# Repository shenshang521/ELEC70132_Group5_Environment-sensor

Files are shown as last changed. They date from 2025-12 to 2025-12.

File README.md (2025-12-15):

Environmental Sensor Board Files
Imperial College London, Dep. of Electrical and Electronic Engineering,
ELEC70132 - Laboratory in Sensor Systems, Group 5
------------------------------------------------------------------------
# ESP32 Environmental Sensor Hub & IoT Data System

## Project Overview
This repository contains the source code and documentation for an ESP32-based Environmental Sensor Hub. This project is submitted as part of the MSc coursework at **Imperial College London**.

The system is a complete **IoT solution** that integrates:
1.  **Edge Device (ESP32):** Monitors environmental conditions (BME680), air quality, distance (ToF), and geolocation (GPS).
2.  **Web Interface:** Hosted directly on the ESP32 for real-time visualization.
3.  **PC Integration (Python):** A desktop application to wirelessly collect sensor data into a database and export it for analysis (Excel/CSV).

## Key Features
*   **Multi-Sensor Fusion:** Reads Temperature, Humidity, Pressure, Gas Resistance (IAQ), Distance, and GPS location simultaneously.
*   **Real-Time Web Dashboard:** Uses **Server-Sent Events (SSE)** to push data to browsers without page refreshes.
*   **Wireless Data Logging (Python):** Python scripts allow for long-term data collection over WiFi into an SQLite database.
*   **Data Analysis Ready:** Includes a tool to export database records to `.csv` format for Excel/MATLAB analysis.
*   **Local Backup:** Automated CSV logging to an onboard SD card for redundancy.
*   **Visual Feedback:** OLED display showing status, IP address, and sensor readings.

## Hardware Requirements
*   **Microcontroller:** ESP32 Development Board
*   **Sensors:** Adafruit BME680, VL53L4CX (ToF), GPS Module (I2C)
*   **Display:** SSD1306 128x64 OLED (I2C)
*   **Storage:** MicroSD Card Module
*   **Connectivity:** WiFi (2.4GHz)

## Dependencies (Arduino IDE)
Please install the following libraries via the Arduino Library Manager:
*   ESPAsyncWebServer
*   AsyncTCP
*   Adafruit SSD1306
*   Adafruit GFX
*   Adafruit BME680 Library
*   Adafruit GPS Library
*   VL53L4CX

## Pin Configuration
| Component | ESP32 Pin | Protocol | Notes |
|---|---|---|---|
| **OLED Display** | SDA / SCL | I2C | Address: 0x3D |
| **BME680** | SDA / SCL | I2C | Default Address |
| **VL53L4CX** | SDA / SCL | I2C | Default Address |
| **GPS Module** | SDA / SCL | I2C | Address: 0x10 |
| **SD Card CS** | GPIO 5 | SPI | Chip Select |
| **SD Card SCK** | GPIO 18 | SPI | VSPI |
| **SD Card MISO** | GPIO 19 | SPI | VSPI |
| **SD Card MOSI** | GPIO 23 | SPI | VSPI |

## Setup Instructions

### ESP32 Configuration
1. Open `src/main/secrets.h`.
2. Replace `YOUR_WIFI_SSID` and `YOUR_WIFI_PASSWORD` with your actual WiFi credentials before flashing the code.
3. Upload the code to your ESP32.
4. Note the IP Address displayed on the OLED screen after startup.

### Python Configuration
1. Open `python_scripts/receive.py`.
2. Find the `ESP32_IP` variable (or URL setting).
3. Update it to match the IP address shown on your ESP32's OLED screen.
4. Run the script to start logging data.

## Project Structure
```text
ESP32_Sensor_Project/
├── src/
│   └── main/                  # Arduino Sketch Folder
│       ├── main.ino           # Main Firmware
│       ├── secrets.h          # WiFi Credentials (Template)
│       └── index_html.h       # Web Frontend (HTML/JS)
├── python_scripts/
│   ├── receive.py             # Rx Data from ESP32 -> SQLite DB
│   └── export_data.py         # Convert DB -> CSV/Excel
├── docs/
│   └── Environmental Sensor Report - Final.pdf             # Coursework Report
├── hardware/
│   └── Environmental_PCB_Group5.epro  # PCB Design 
└── README.md                  # Documentation
├── previous code/             # Development History & Iterations
│   ├── Cali_friday            # Initial sensor calibration tests
│   ├── Calibriation_Environment_sensor # Detailed calibration logic
│   ├── Environment_WIFI_SD_HTML # Early integration (Web+SD)
│   ├── environment            # Basic environmental sensor drivers
│   ├── python_scripts         # Legacy/Old Python scripts
│   └── sd_tof                 # Distance sensor & SD 
├── 3D Enclosure/              # Mechanical Design Files (.stl)
│   ├── PCB_Enclosure_Body.stl # Main housing for electronics
│   ├── PCB_Cover.stl          # Lid for the sensor unit
│   ├── Power_bank_body.stl    # Holder for external battery
│   └── Power_bank_cover.stl   # Lid for the battery

The original intention for this project was was to develop a single-PCB
sensor system capable of wired and wireless communication (via a Wi-Fi
connection). All the relevant files for this project can be found in
this public GitHub repository, including the final report.

For more details, feel free to contact: tr525@ic.ac.uk

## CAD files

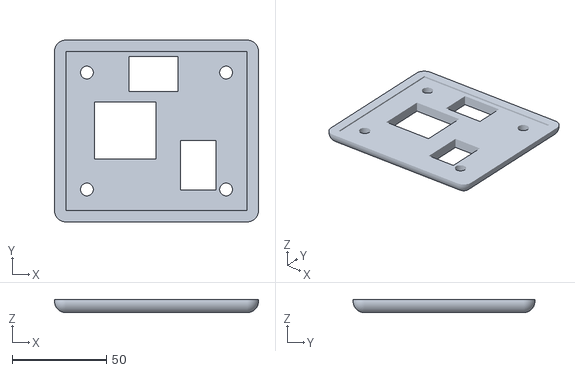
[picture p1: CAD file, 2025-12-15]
3D Enclosure/PCB_Cover.stl
108.5 x 96.7 x 7.00

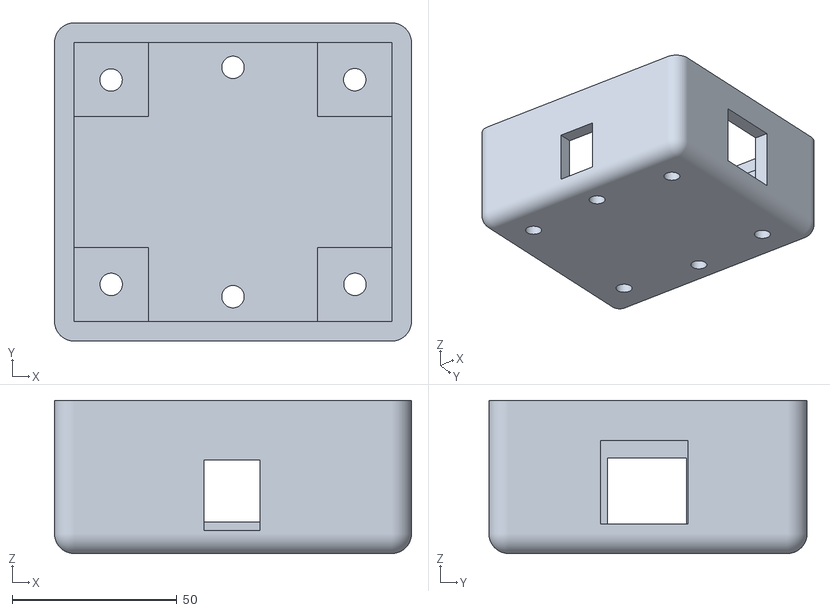
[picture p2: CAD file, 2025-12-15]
3D Enclosure/PCB_Enclosure_Body.stl
108.5 x 96.7 x 46.5

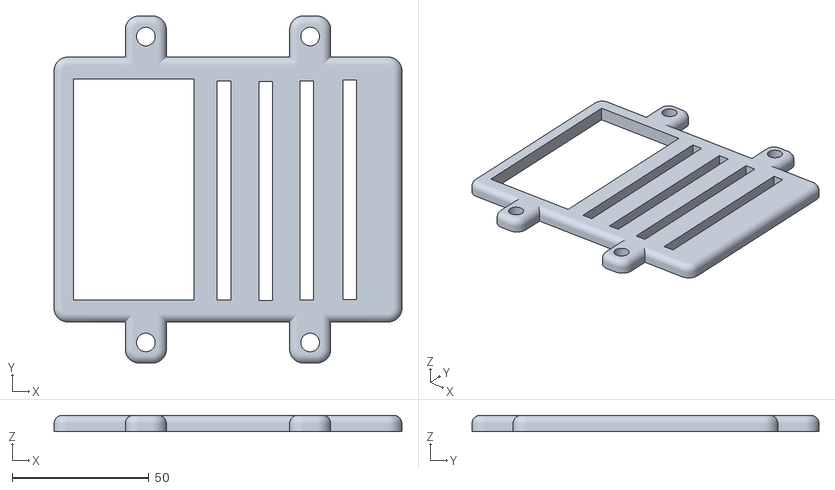
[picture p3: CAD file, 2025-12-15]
3D Enclosure/Power_bank_cover.stl
127.0 x 126.7 x 6.00

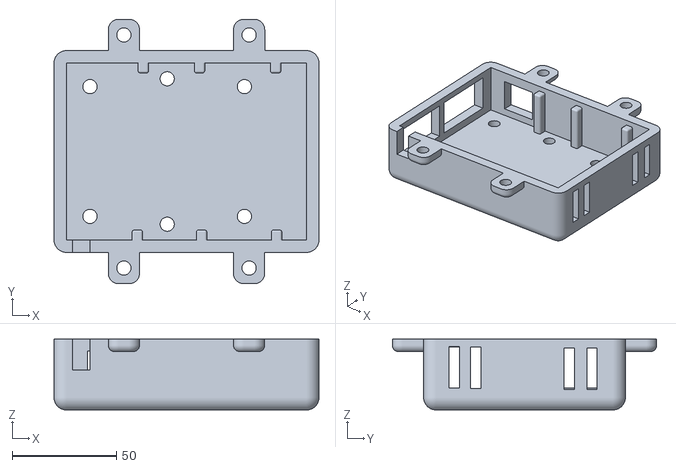
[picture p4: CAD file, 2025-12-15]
3D Enclosure/Power_bank_body.stl
127.0 x 126.7 x 34.0

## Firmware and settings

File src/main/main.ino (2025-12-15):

#include <WiFi.h>
#include <ESPAsyncWebServer.h>
#include <AsyncTCP.h>
#include <Wire.h>
#include <SPI.h>
#include <Adafruit_SSD1306.h>
#include <Adafruit_GFX.h>
#include <Adafruit_BME680.h>
#include <Adafruit_GPS.h>
#include <vl53l4cx_class.h>
#include <FS.h>
#include <SD.h>
#include <time.h> 
#include "secrets.h"     
#include "index_html.h"  

// ==========================================
// MODULE 1: Global Configurations
// ------------------------------------------
// NTP Settings and Hardware Pin Definitions
// =========================================
const char* ntpServer = "pool.ntp.org";
const char* timeZone = "GMT0BST,M3.5.0/1,M10.5.0";
#define SD_CS_PIN 5 
#define SCREEN_WIDTH 128
#define SCREEN_HEIGHT 64
#define GPS_I2C_ADDRESS 0x10

// ==========================================
// MODULE 2: Hardware Objects & Variables
// ------------------------------------------
// Initialization of global objects for sensors, display, and web server.
// ==========================================
Adafruit_SSD1306 display(SCREEN_WIDTH, SCREEN_HEIGHT, &Wire, -1);
Adafruit_BME680 bme; 
VL53L4CX sensor_vl53l4cx_sat;
Adafruit_GPS GPS(&Wire);
AsyncWebServer server(80);
AsyncEventSource events("/events");

unsigned long lastMeasurement = 0;
const unsigned long interval = 5000; 
bool sdReady = false;


// ==========================================
// MODULE 3: Helper Functions
// ------------------------------------------
// Utility functions used by the main logic.
// ==========================================
String getFormattedTime() {
  struct tm timeinfo;
  if(!getLocalTime(&timeinfo)){ return "Time Error"; }
  char timeStringBuff[30];
  strftime(timeStringBuff, sizeof(timeStringBuff), "%Y-%m-%d %H:%M:%S", &timeinfo);
  return String(timeStringBuff);
}

// ==========================================
// MODULE 4: SETUP FUNCTION
// ------------------------------------------
// Hardware initialization and Network connection sequence.
// ==========================================
void setup() {
  Serial.begin(115200);
  delay(1000); 
  Serial.println("\n System Starting...");

  Wire.begin();

  // 4.1 OLED 
  if (!display.begin(SSD1306_SWITCHCAPVCC, 0x3D)) { 
    Serial.println(" OLED Error");
  } else {
    display.clearDisplay();
    display.setTextSize(1);
    display.setTextColor(SSD1306_WHITE);
    display.setCursor(0, 0);
    display.println("Init Hardware...");
    display.display();
  }

  // 4.2 SD Card 
  if (!SD.begin(SD_CS_PIN)) {
    Serial.println(" SD Mount Failed");
    sdReady = false;
  } else {
    Serial.println(" SD Mounted");
    sdReady = true;
    if (!SD.exists("/data.csv")) {
      File file = SD.open("/data.csv", FILE_WRITE);
      if (file) {
        file.println("Timestamp,Temp_C,Hum_%,Press_hPa,Gas_KOhms,AQ_%,Dist_mm,Lat,Lon,Alt_m");
        file.close();
      }
    }
  }

  //  4.3 WiFi and Time Sync
  display.clearDisplay(); display.setCursor(0,0); display.println("Connecting WiFi..."); display.display();
  WiFi.begin(ssid, password);
  WiFi.setSleep(false);
  
  int retry = 0;
  while (WiFi.status() != WL_CONNECTED && retry < 20) {
    delay(500); Serial.print("."); retry++;
  }

  if (WiFi.status() == WL_CONNECTED) {
    Serial.println("\n WiFi Connected!");
    configTime(0, 0, ntpServer);
    setenv("TZ", timeZone, 1);
    tzset();
    struct tm timeinfo;
    int retryTime = 0;
    while (!getLocalTime(&timeinfo) && retryTime < 10) {
      Serial.print("."); delay(500); retryTime++;
    }
    Serial.println("\n Time Synced!");
  } 

  // 4.4 Sensors
  if (!bme.begin()) Serial.println(" BME688 Error");
  bme.setTemperatureOversampling(BME680_OS_8X);
  bme.setHumidityOversampling(BME680_OS_2X);
  bme.setPressureOversampling(BME680_OS_4X);
  bme.setIIRFilterSize(BME680_FILTER_SIZE_3);
  bme.setGasHeater(320, 150);

  sensor_vl53l4cx_sat.setI2cDevice(&Wire);
  sensor_vl53l4cx_sat.InitSensor(VL53L4CX_DEFAULT_DEVICE_ADDRESS);
  sensor_vl53l4cx_sat.VL53L4CX_StartMeasurement();

  if (!GPS.begin(GPS_I2C_ADDRESS)) Serial.println(" GPS Error");
  GPS.sendCommand(PMTK_SET_NMEA_OUTPUT_RMCGGA);
  GPS.sendCommand(PMTK_SET_NMEA_UPDATE_1HZ);

  // 4.5 Web Server
  server.addHandler(&events);
  server.on("/", HTTP_GET, [](AsyncWebServerRequest *r){ r->send_P(200, "text/html", index_html); });
  server.on("/download", HTTP_GET, [](AsyncWebServerRequest *r){ if(SD.exists("/data.csv")) r->send(SD, "/data.csv", "text/csv", true); else r->send(404); });
  server.on("/delete", HTTP_GET, [](AsyncWebServerRequest *r){ 
    SD.remove("/data.csv"); 
    File f = SD.open("/data.csv", FILE_WRITE); 
    if(f){f.println("Timestamp,Temp_C,Hum_%,Press_hPa,Gas_KOhms,AQ_%,Dist_mm,Lat,Lon,Alt_m"); f.close();}
    r->send(200, "text/plain", "Deleted"); 
  });
  
  server.begin();
}

// ==========================================
// MODULE 5: LOOP FUNCTION
// ------------------------------------------
// Main execution loop.
// 1. GPS Parsing
// 2. Sensor Reading (Interval: 5s)
// 3. Data Processing & Logging
// 4. Interface Updates (Web & OLED)
// ==========================================
void loop() {
  GPS.read();
  if (GPS.newNMEAreceived()) GPS.parse(GPS.lastNMEA());

  if (millis() - lastMeasurement >= interval) {
    lastMeasurement = millis();

    bme.performReading();
    float temp = bme.temperature;
    float hum = bme.humidity;
    float press = bme.pressure / 100.0;
    float gas = bme.gas_resistance / 1000.0;

    float aq_score = 0.0;
    if (gas >= 50.0) aq_score = 100.0;       // good air quality
    else if (gas <= 5.0) aq_score = 0.0;     // poor air quality
    else aq_score = (gas - 5.0) * (100.0 / 45.0); // Interval Check
    // -------------------------------------------------------------

    VL53L4CX_MultiRangingData_t MultiRangingData;
    uint8_t NewDataReady = 0;
    int distance = 0;
    sensor_vl53l4cx_sat.VL53L4CX_GetMeasurementDataReady(&NewDataReady);
    if (NewDataReady) {
      sensor_vl53l4cx_sat.VL53L4CX_GetMultiRangingData(&MultiRangingData);
      if (MultiRangingData.NumberOfObjectsFound > 0) distance = MultiRangingData.RangeData[0].RangeMilliMeter;
      sensor_vl53l4cx_sat.VL53L4CX_ClearInterruptAndStartMeasurement();
    }

    float lat = GPS.latitudeDegrees;
    float lon = GPS.longitudeDegrees;
    float alt = GPS.altitude;
    if (isnan(temp)) temp = 0;

    String timeStr = getFormattedTime();

    //  SD CARD LOGGING 
    bool writeSuccess = false;
    if (sdReady) {
      File file = SD.open("/data.csv", FILE_APPEND);
      if (file) {
        file.print(timeStr); file.print(",");
        file.print(temp); file.print(",");
        file.print(hum); file.print(",");
        file.print(press); file.print(",");
        file.print(gas); file.print(",");
        file.print(aq_score, 0); file.print(","); // 写入 AQ
        file.print(distance); file.print(",");
        file.print(lat, 6); file.print(",");
        file.print(lon, 6); file.print(",");
        file.println(alt);
        file.close();
        writeSuccess = true;
      }
    }

     // SERIAL 
    Serial.println("\n---  " + timeStr + " ---");
    Serial.printf("Temp:    %.2f C\n", temp);
    Serial.printf("Hum:     %.2f %%\n", hum);       
    Serial.printf("Press:   %.2f hPa\n", press);    
    Serial.printf("Gas:     %.2f KOhms\n", gas);
    Serial.printf("AirQual: %.0f %%\n", aq_score); // AQ 
    Serial.printf("Dist:    %d mm\n", distance);
    
    if (lat != 0.0) {
        Serial.printf("GPS:     Lat: %.6f, Lon: %.6f, Alt: %.2fm\n", lat, lon, alt);
    } else {
        Serial.println("GPS:     No Fix (Searching...)");
    }
    
    Serial.printf("SD:      %s\n", writeSuccess ? " OK" : " Error");
    Serial.printf("IP:      %s\n", WiFi.localIP().toString().c_str());

    // Web Send
    String json = "{";
    json += "\"time\":\"" + timeStr + "\","; 
    json += "\"temp\":" + String(temp, 1) + ",";
    json += "\"hum\":" + String(hum, 0) + ",";
    json += "\"press\":" + String(press, 1) + ",";
    json += "\"gas\":" + String(gas, 1) + ",";
    json += "\"aq\":" + String(aq_score, 0) + ","; // AQ
    json += "\"dist\":" + String(distance) + ",";
    json += "\"lat\":" + String(lat, 6) + ",";
    json += "\"lon\":" + String(lon, 6) + ",";
    json += "\"alt\":" + String(alt, 1) + ",";
    json += "\"sd\":" + String(writeSuccess ? 1 : 0);
    json += "}";
    events.send(json.c_str(), "update", millis());

    // OLED Display
    display.clearDisplay();
    display.setCursor(0, 0);
    display.println(WiFi.localIP()); 
    
    if (timeStr.length() > 8) display.println(timeStr.substring(11));
    else display.println("Time Syncing..");

    display.printf("T:%.1f H:%.0f%%\n", temp, hum);
    display.printf("P:%.0f AQ:%.0f%%\n", press, aq_score); 
    display.printf("Dist: %d mm\n", distance);
    
    if (lat != 0.0) display.printf("GPS:OK SD:%s\n", writeSuccess ? "OK" : "X");
    else display.printf("GPS:No SD:%s\n", writeSuccess ? "OK" : "X");
    
    display.display();
  }
}

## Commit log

2025-12-15 Final Firmware: ESP32 Sensor System and Web
    Files included:
    main.ino: Core logic for sensor reading (GPS, BME680, VL53L4CX), SD card logging, and OLED display.
    index_html.h: Frontend web interface code.
    secrets.h: WiFi configuration template.
    (Python data processing scripts will be uploaded in a separate commit)
2025-12-15 the final verified firmware for the ESP32.
    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
2025-12-15 Add files via upload
    The PCB for this project is housed in a custom 3D-printed enclosure designed in FreeCAD. Its main role is to protect the circuit and prevent accidental contact with the components. PLA was chosen as the material because it’s easy to print and strong enough for indoor electronics. The enclosure is made of a base and a screw-on lid, which makes it simple to open when the PCB needs to be checked or maintained.
    The design includes openings where the PCB components need to interact with the environment. There are cut-outs for the distance sensor, pressure sensor, and gas sensor, so they can work without obstruction. The graphic OLED display has its own opening for easy v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
    [PCB_Cover.stl, PCB_Enclosure_Body.stl, Power_bank_body.stl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]
